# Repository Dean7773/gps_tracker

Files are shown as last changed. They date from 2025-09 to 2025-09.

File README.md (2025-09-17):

# 🛰️ GPS Tracker на ESP32

**GPS трекер с WiFi, SD картой и OLED дисплеем на базе ESP32**

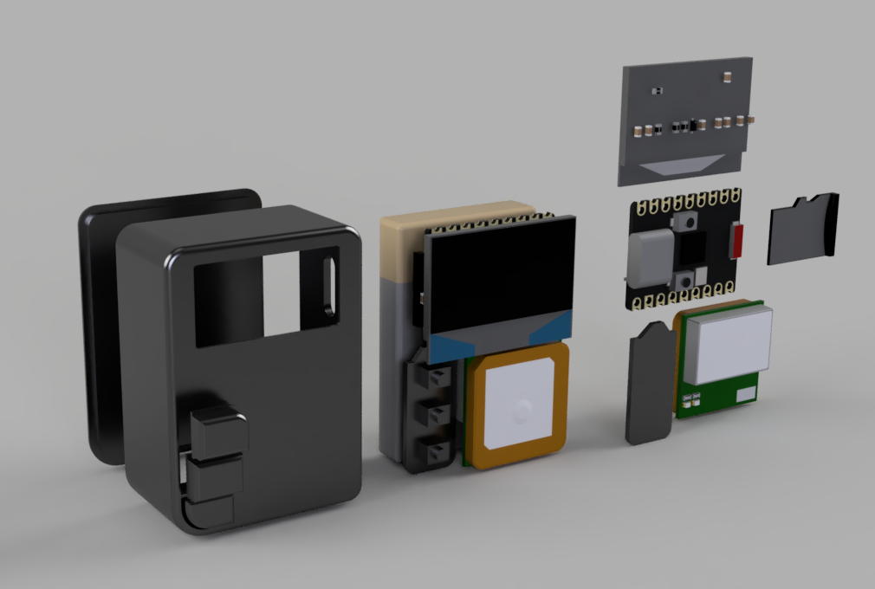
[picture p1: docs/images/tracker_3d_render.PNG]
ESP32 Tracker


## 📋 Описание

Это полнофункциональный GPS трекер, разработанный на ESP32-C3 с интуитивно понятным интерфейсом на OLED дисплее. Устройство способно записывать треки в высоком качестве, синхронизироваться с сервером через WiFi и управлять данными через удобное меню.

## Связанные проекты

- **[GPS Location Tracker](https://github.com/Dean7773/location_tracker)** - Сервис для просмотра маршрутов записанных при помощи GPS устройств.

## ✨ Основные возможности

### 🗺️ **GPS Трекинг**
- **Высокоточная запись** треков с фильтрацией по расстоянию (≥2м) и углу поворота (≥20°)
- **Поддержка GPS модуля** Cyclone M10-18 с автоматическим парсингом NMEA
- **Реальное время** из GPS спутников с поддержкой часовых поясов
- **Информация о спутниках** и качестве сигнала
- **Запись координат, высоты, скорости** и временных меток

### 📱 **Интерфейс и управление**
- **OLED дисплей 128x64** с четким отображением информации
- **Трехкнопочное управление** (UP/OK/DOWN) через аналоговый вход
- **Интуитивное меню** с навигацией по разделам
- **Информативные экраны** с детальной GPS информацией
- **Индикация статуса** записи и подключений

### 💾 **Хранение данных**
- **SD карта** для локального хранения треков
- **JSON формат** треков для совместимости с веб-сервисами
- **Управление файлами** - просмотр, удаление, форматирование
- **Тестирование SD карты** с диагностикой

### 🌐 **WiFi и синхронизация**
- **Автоматическое сканирование** и подключение к WiFi сетям
- **Сохранение до 3 сетей** в EEPROM с автоматическим переподключением
- **JWT авторизация** на сервере для безопасной передачи данных
- **Отправка треков чанками** для надежной передачи больших файлов
- **API интеграция** с веб-сервером для синхронизации данных

### 🔧 **Технические особенности**
- **Умная фильтрация точек** для оптимизации размера треков
- **Расчет расстояний и углов** поворота для точной записи
- **Обработка ошибок** и восстановление после сбоев
- **Энергоэффективность** с оптимизированным кодом
- **Модульная архитектура** для легкого расширения функций

## 🖼️ Интерфейс устройства

### Главное меню
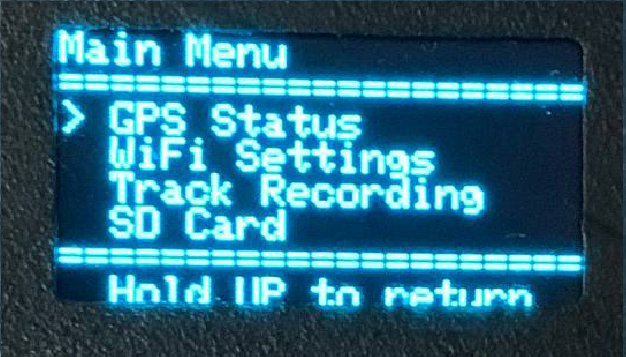
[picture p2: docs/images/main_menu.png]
Main Menu


*Главное меню с навигацией по основным разделам*

### GPS информация
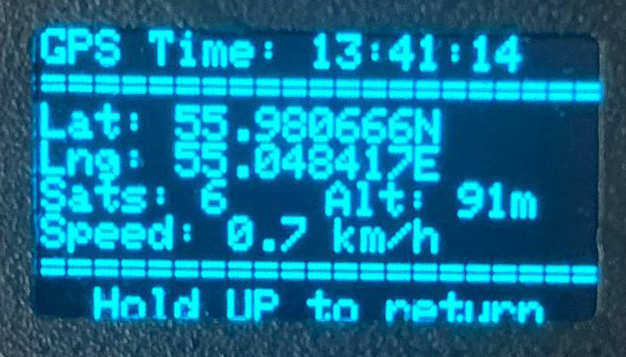
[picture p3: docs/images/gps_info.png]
GPS Info


*Детальная информация GPS: координаты, спутники, время, скорость*

### Запись трека
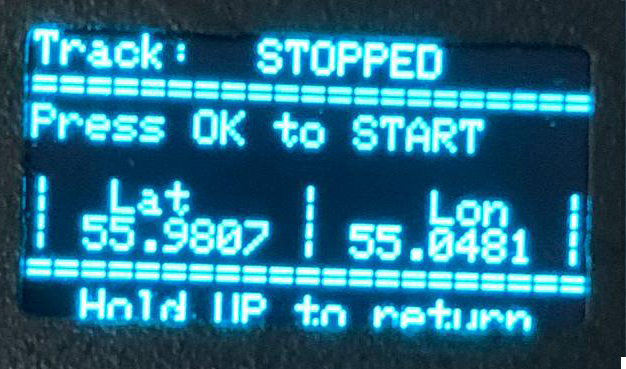
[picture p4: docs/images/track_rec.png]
Track Recording


*Интерфейс записи трека с индикацией количества точек*

### WiFi настройки
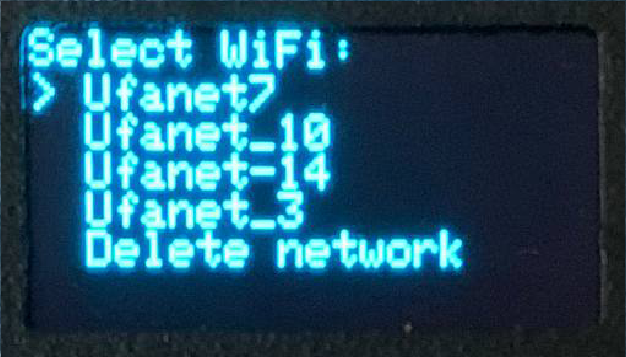
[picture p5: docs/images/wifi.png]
WiFi


*Управление WiFi подключениями и синхронизация с сервером*

### SD карта
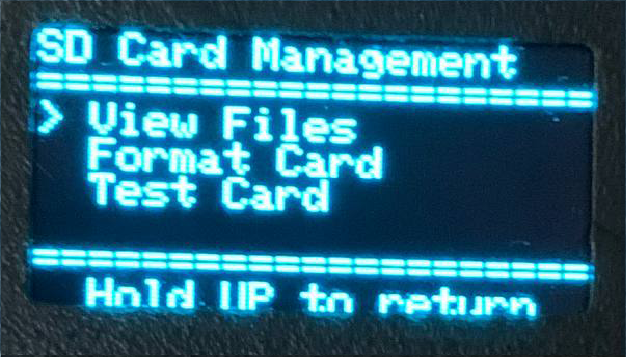
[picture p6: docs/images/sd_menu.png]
SD Menu


*Управление файлами на SD карте*

## 🔌 Аппаратная часть

### Компоненты
- **ESP32** (любая совместимая плата)
- **GPS модуль** Cyclone M10-18 (или совместимый)
- **OLED дисплей** 128x64 (SSD1306)
- **SD карта модуль** с поддержкой SPI
- **3 кнопки** для управления (через делитель напряжения)

### Схема подключения

```
ESP32 Pinout:
├── GPIO0  → Аналоговый вход кнопок (ADC1_CH1)
├── GPIO7  → SD Card CS (Chip Select)
├── GPIO20 → GPS RX (ESP32 RX ← GPS TX)
├── GPIO21 → GPS TX (ESP32 TX → GPS RX)
├── SDA    → OLED SDA
├── SCL    → OLED SCL
└── 3.3V/GND → Питание модулей
```

### Кнопки (делитель напряжения)
```
3.3V ─┬─ R1 ─┬─ UP Button ─┬─ GND
      │       │             │
      ├─ R2 ─┼─ OK Button ─┤
      │       │             │
      └─ R3 ─┴─ DOWN Button ┘
              │
              └─ GPIO0 (ADC)
```

## 🖥️ Внешний вид устройства
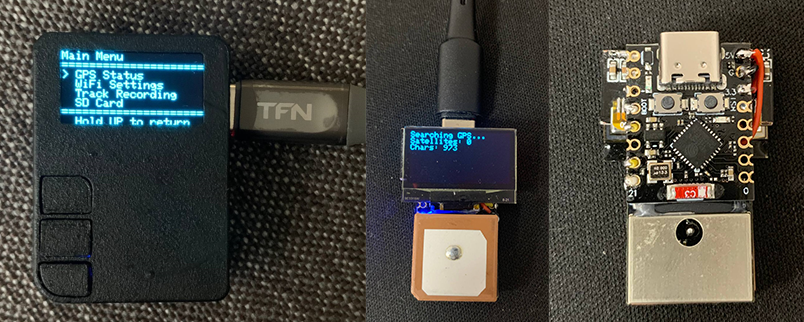
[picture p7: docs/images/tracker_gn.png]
Tracker Main


*Это макет, спроектированный на коленке, дизайн будет полностью изменен*

### Детали корпуса
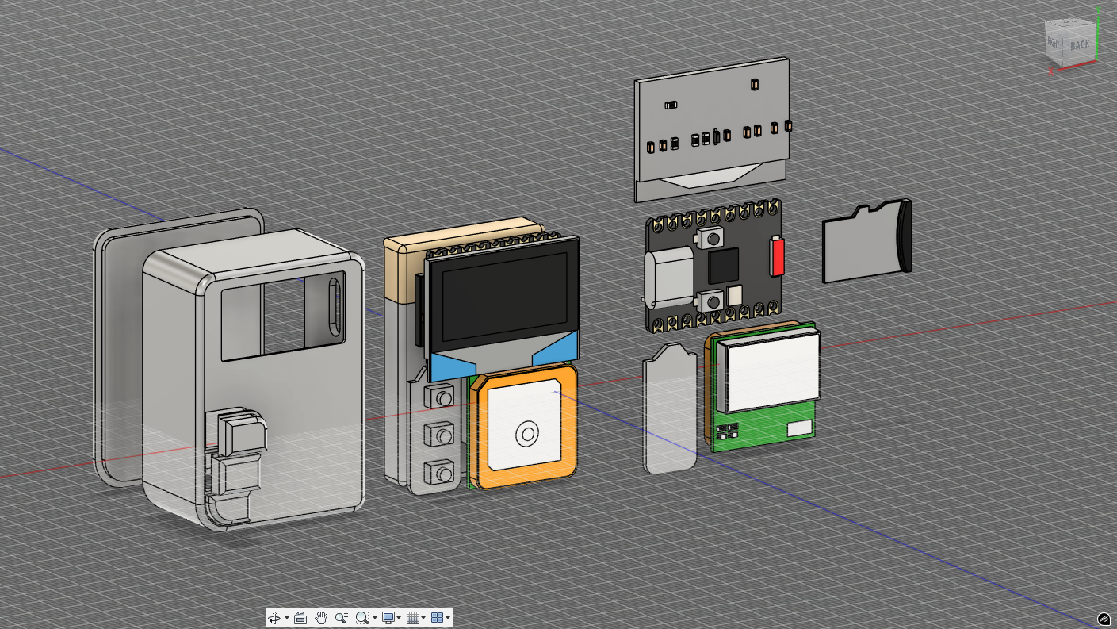
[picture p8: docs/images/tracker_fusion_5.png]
Tracker Top


*Части корпуса с размещением компонентов*

## 🚀 Установка и настройка

### 1. Установка Arduino IDE и библиотек

```cpp
// Необходимые библиотеки:
#include "EncButton.h"        // Обработка кнопок
#include <Adafruit_SSD1306.h> // OLED дисплей
#include <TinyGPS++.h>        // GPS парсинг
#include <WiFi.h>             // WiFi ESP32
#include <HTTPClient.h>       // HTTP клиент
#include <ArduinoJson.h>      // JSON обработка
#include <SD.h>               // SD карта
```

### 2. Настройка конфигурации

Отредактируйте `firmware/config.h`:

```cpp
// Настройка сервера
#define SERVER_URL "http://your-server.com:8000"

// Настройка пинов (при необходимости)
#define GPS_RX 20
#define GPS_TX 21
#define SD_CS_PIN 7
```

### 3. Прошивка устройства

1. Подключите ESP32 к компьютеру
2. Откройте `firmware/gps_tracker.ino` в Arduino IDE
3. Выберите плату ESP32 Dev Module
4. Загрузите прошивку

### 4. Первый запуск

1. Вставьте отформатированную SD карту
2. Включите устройство
3. Дождитесь GPS фикса (может занять 1-2 минуты)
4. Настройте WiFi через меню
5. Авторизация на сервере (требуется только для отправки треков)

## 🔧 Настройка и калибровка

### Калибровка кнопок
Измерьте напряжения на GPIO0 при нажатии кнопок и обновите в `config.h`:
```cpp
#define UP_MIN 1307    // Минимальное значение для UP
#define UP_MAX 1507    // Максимальное значение для UP
#define OK_MIN 2750    // Минимальное значение для OK
#define OK_MAX 2950    // Максимальное значение для OK
#define DOWN_MIN 4080  // Минимальное значение для DOWN
#define DOWN_MAX 4180  // Максимальное значение для DOWN
```

### Настройка фильтрации треков
В `tracks.ino` можно изменить параметры фильтрации:
```cpp
if (dist >= 2.0) {          // Минимальное расстояние между точками (метры)
  shouldWrite = true;
}
if (angle >= 20.0) {        // Минимальный угол поворота (градусы)
  shouldWrite = true;
}
```

## 📈 Производительность

### Характеристики записи
- **Точность GPS**: до 1-3 метров (зависит от условий)
- **Частота записи**: адаптивная (2м или 20° поворота)
- **Размер трека**: ~500 точек на км (зависит от маршрута)
- **Время работы**: 4-5 часов записи (с батареей 1000mAh)

### Объем данных
- **1 час записи**: ~5000 точек (~570 KB)
- **SD карта 1GB**: ~1,800 часов записи (75 дней)
- **Чанк для отправки**: 50 точек (~5.6 KB)

## 🛠️ Структура проекта

```
gps_tracker/
├── firmware/
│   ├── gps_tracker.ino    # Основной файл
│   ├── config.h           # Конфигурация
│   ├── menu.ino           # Интерфейс меню
│   ├── gps.ino            # GPS функции
│   ├── tracks.ino         # Запись и отправка треков
│   ├── wifi.ino           # WiFi управление
│   ├── sd.ino             # SD карта функции
│   └── auth.ino           # Авторизация
├── docs/
│   └── images/            # Скриншоты интерфейса
└── README.md
```

## 🐛 Устранение неполадок

### Частые проблемы

**GPS не получает фикс:**
- Проверьте подключение GPS модуля
- Убедитесь в наличии видимости неба
- Подождите 2-3 минуты для холодного старта

**SD карта не читается:**
- Проверьте формат (FAT32)
- Убедитесь в правильном подключении SPI
- Попробуйте другую SD карту

**WiFi не подключается:**
- Проверьте правильность пароля
- Убедитесь в поддержке 2.4GHz сети
- Перезагрузите устройство

**Кнопки не реагируют:**
- Проверьте делитель напряжения
- Откалибруйте значения в config.h
- Проверьте подключение к GPIO0

## 📝 Лицензия

Этот проект распространяется под лицензией MIT. См. файл [LICENSE](LICENSE) для подробностей.

## 🤝 Участие в разработке

Приветствуются любые улучшения! Для участия:

1. Сделайте Fork проекта
2. Создайте ветку для новой функции
3. Внесите изменения и протестируйте
4. Отправьте Pull Request

## 📞 Поддержка

Если у вас есть вопросы или предложения:
- Создайте Issue в GitHub
- Опишите проблему максимально подробно
- Приложите скриншоты и логи если возможно
- Напишите в тг: https://t.me/wlkks

## 🎯 Планы развития

- [ ] Энергосбережение и режимы сна
- [ ] Bluetooth интерфейс для настройки
- [ ] Поддержка дополнительных GPS форматов
- [ ] Веб-интерфейс для управления
- [ ] Мобильное приложение
- [ ] Поддержка LoRaWAN для дальней связи

---

**Создано с ❤️ для сообщества разработчиков GPS решений**

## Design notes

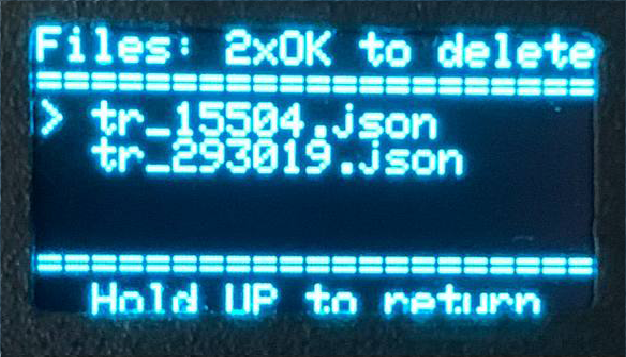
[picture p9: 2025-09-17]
docs/images/tracks_fs.png

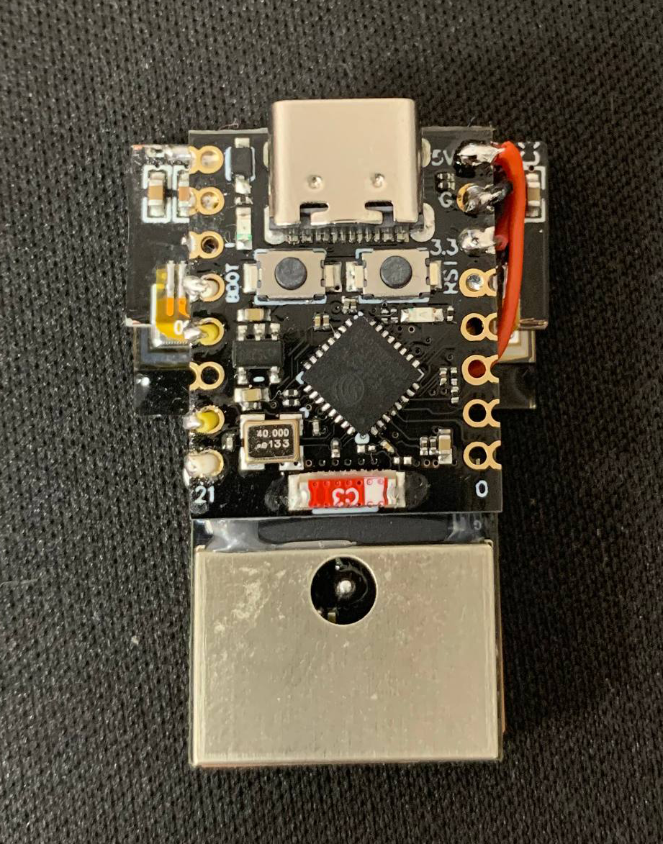
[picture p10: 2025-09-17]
docs/images/tracker_bttm.png

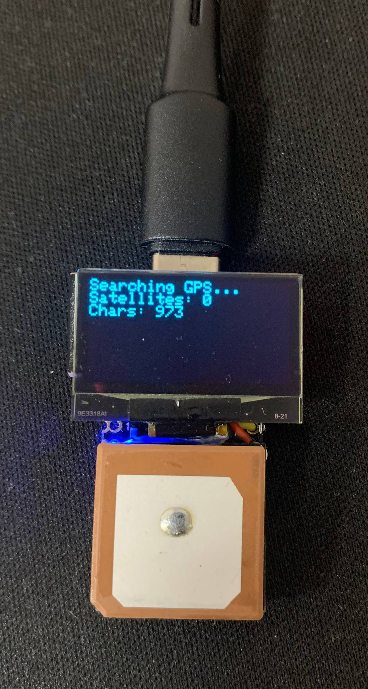
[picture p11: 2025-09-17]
docs/images/tracker_on.png

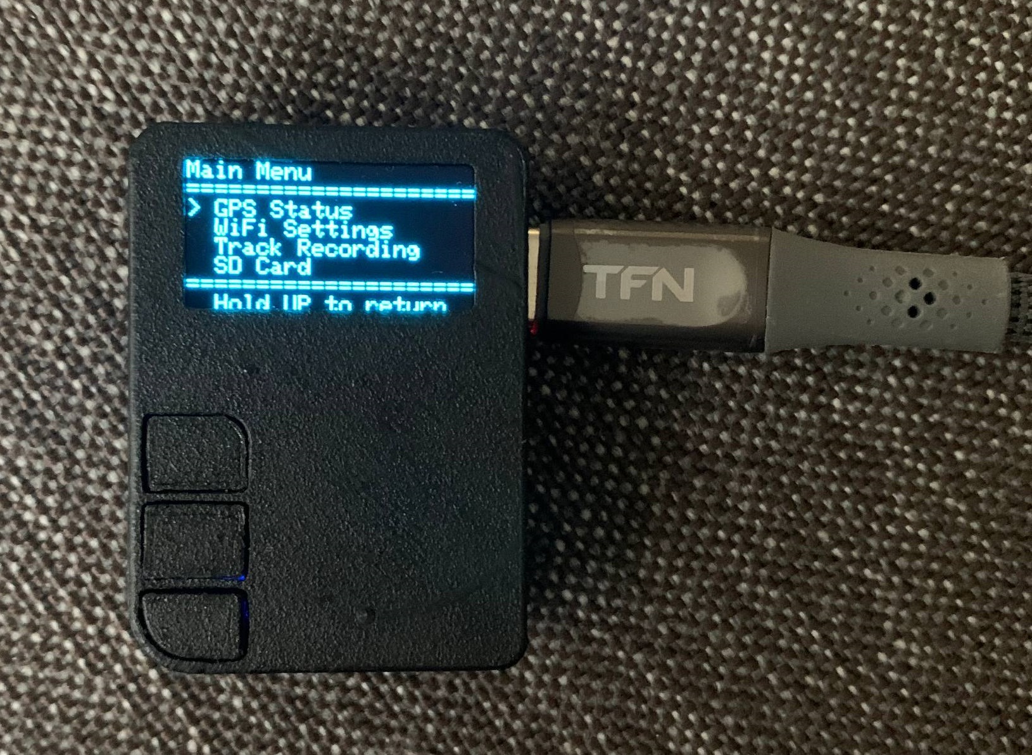
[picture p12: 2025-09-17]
docs/images/tracker_main.png

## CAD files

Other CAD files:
fusion360/gps_tracker.f3d

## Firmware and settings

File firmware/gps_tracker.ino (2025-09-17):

#include "EncButton.h"
#include <SPI.h>
#include <Wire.h>
#include <Adafruit_GFX.h>
#include <Adafruit_SSD1306.h>
#include <TinyGPS++.h>
#include <WiFi.h>
#include <HTTPClient.h>
#include <ArduinoJson.h>
#include <EEPROM.h>
#include <FS.h>
#include <SD.h>
#include <HardwareSerial.h>
#include <math.h>

#include "config.h"

// ============================================================================
// ИНИЦИАЛИЗАЦИЯ
// ============================================================================

// Инициализация OLED, GPS
Adafruit_SSD1306 display(SCREEN_WIDTH, SCREEN_HEIGHT, &Wire, OLED_RESET);
HardwareSerial gpsSerial(1);
TinyGPSPlus gps;

// Инициализация кнопок
VirtButton up;
VirtButton ok;
VirtButton down;

// ============================================================================
// СТРУКТУРЫ И ПЕРЕЧИСЛЕНИЯ
// ============================================================================

// Структура для хранения WiFi credentials
struct WiFiCred {
  char ssid[WIFI_CRED_MAXLEN];
  char pass[WIFI_CRED_MAXLEN];
};

// Перечисление для уровней меню
enum MenuLevel { MAIN, WIFI, TRACK, SDCARD, GPS };
MenuLevel menuLevel = MAIN;

// Переменные для указателей меню
uint8_t mainPointer = 0; // 0-GPS, 1-WiFi, 2-Track, 3-SD Card
uint8_t wifiPointer = 0; // 0-Connect/Connected, 1-Auth, 2-Send track, 3-Send all tracks
uint8_t sdPointer = 0;   // 0-Files, 1-Format, 2-Test
uint32_t elapsedTime = 0; // Оставляем для возможного использования в будущем
bool flag_track = false;
bool wifiConnected = false;

// WiFi меню
String ssidList[10];
int networksFound = 0;

// Символы для ввода пароля
const char symbols[] = "0123456789abcdefghijklmnopqrstuvwxyzABCDEFGHIJKLMNOPQRSTUVWXYZ!@#$%^&*()-_=+[]{};:,.<>/?";
const int symbolsCount = sizeof(symbols) - 1;

// Глобальные переменные для авторизации
String jwtToken = "";
String authUser = "";
String authPass = "";

// Переменные для отображения
static uint32_t lastDisplayUpdate = 0;
const uint32_t DISPLAY_UPDATE_INTERVAL = 500; // Обновление каждые 500мс

// Добавляем флаг для отрисовки
bool needRedraw = true;

// GPS данные для собственной обработки
struct GPSData {
  float latitude = 0;
  float longitude = 0;
  float speed = 0;
  uint8_t hours = 0;
  uint8_t minutes = 0;
  uint8_t seconds = 0;
  uint8_t satellites = 0;
  bool hasFix = false;
} gpsData;

// Переменные для записи трека
String currentTrackFile = "";
uint32_t trackPoints = 0;
uint32_t lastTrackWrite = 0;
uint32_t trackStartTime = 0; // Время начала записи трека
bool isRecording = false; // Флаг активной записи трека

// Переменные для фильтрации точек
float lastLat = 0.0, lastLon = 0.0;
float prevLat = 0.0, prevLon = 0.0; // Предыдущая точка для расчета угла
bool hasLastPoint = false;
bool hasPrevPoint = false; // Есть ли предыдущая точка для расчета угла


// --- Прототипы ---
int selectWiFiNetwork();
void inputPassword(char* password, int maxLen);
void connectToWiFi(const char* ssid, const char* password);
void disconnectWiFi();
void drawMainMenu();
void drawWiFiMenu();
void drawTrackMenu();
void drawSDCardMenu();
void inputString(char* buffer, int maxLen, const char* label, bool hide = false);
bool authorizeOnServer(const char* login, const char* pass, String& token, String& message);
void saveWiFiCredential(const char* ssid, const char* pass);
void loadWiFiCredentials(WiFiCred* creds);
void viewSDFiles();
void formatSDCard();
void testSDCard();
void deleteWiFiCredential(const char* ssid);
bool getSavedWiFiPassword(const char* ssid, char* password);
void configureGPS();
void readUBXData();
void startTrackRecording();
void stopTrackRecording();
void writeTrackPoint();
void sendTrackToServer(const char* filename);


void setup() {
  // Настройка аналогового входа для кнопок
  analogReadResolution(12); // 12-битное разрешение (0-4095)
  
  // Настройка задержки для hasClicks() - можно изменить по желанию
  ok.setClickTimeout(200);    // 400мс для OK (средне)

  display.begin(SSD1306_SWITCHCAPVCC, SCREEN_ADDRESS);
  display.clearDisplay();
  display.setTextSize(1);
  display.setTextColor(SSD1306_WHITE);
  display.setCursor(10, 10);
  display.println("Location tracker");
  display.display();
  delay(500);
  
  // Инициализация GPS через HardwareSerial для ESP32
  gpsSerial.begin(115200, SERIAL_8N1, GPS_RX, GPS_TX);
  delay(500);

  display.clearDisplay();
  display.display();
  drawMainMenu();
}

void loop() {

  // Читаем аналоговое значение кнопок
  int analog = analogRead(ANALOG_PIN);
  
  // Определяем нажатые кнопки
  bool upPressed = (analog >= UP_MIN && analog <= UP_MAX);
  bool okPressed = (analog >= OK_MIN && analog <= OK_MAX);
  bool downPressed = (analog >= DOWN_MIN && analog <= DOWN_MAX);
  
  // Обновляем состояния кнопок
  up.tick(upPressed);
  ok.tick(okPressed);
  down.tick(downPressed);
  
  // Дополнительная обработка кнопок для лучшей реакции
  if (flag_track) {
    up.tick(upPressed);
    ok.tick(okPressed);
    down.tick(downPressed);
  }


  // MAIN MENU
  if (menuLevel == MAIN) {
    if (up.click()) { mainPointer = (mainPointer + 3) % 4; needRedraw = true; }
    if (down.click()) { mainPointer = (mainPointer + 1) % 4; needRedraw = true; }
    if (ok.click()) {
      switch (mainPointer) {
        case 0: 
          menuLevel = GPS; 
          needRedraw = true;
          ok.reset(); 
          break;
        case 1: 
          menuLevel = WIFI; 
          wifiPointer = 0; 
          needRedraw = true; 
          ok.reset();
          break;
        case 2: 
          menuLevel = TRACK; 
          needRedraw = true; 
          ok.reset();
          break;
        case 3: 
          menuLevel = SDCARD; 
          sdPointer = 0; 
          needRedraw = true; 
          ok.reset();
          break;
      }
    }
    static uint32_t uiTimer = 0;
    if (millis() - uiTimer > 5000) { uiTimer = millis(); needRedraw = true; }
  }

  // WIFI SUBMENU
  if (menuLevel == WIFI) {
    int maxPointer = wifiConnected ? 4 : 1;
    if (up.click()) { wifiPointer = (wifiPointer + maxPointer - 1) % maxPointer; needRedraw = true; }
    if (down.click()) { wifiPointer = (wifiPointer + 1) % maxPointer; needRedraw = true; }
    if (ok.click()) {
      if (!wifiConnected) {
        int net = selectWiFiNetwork();
        if (net >= 0) {
          char password[33] = "";
          inputPassword(password, 33);
          connectToWiFi(ssidList[net].c_str(), password);
        }
        needRedraw = true;
      } else {
        switch (wifiPointer) {
          case 0: { // Connected
            display.clearDisplay();
            display.setCursor(0, 0);
            display.println("    Connected!");
            display.println("=====================");
            display.print("  IP: ");
            display.println(WiFi.localIP());
            display.println("");
            display.println(" Push to disconnect");
            display.println("");
            display.println("=====================");
            display.println("  Hold UP to return");
            display.display();
            while (true) {
              int analog = analogRead(ANALOG_PIN);
              bool upPressed = (analog >= UP_MIN && analog <= UP_MAX);
              bool okPressed = (analog >= OK_MIN && analog <= OK_MAX);
              
              up.tick(upPressed);
              ok.tick(okPressed);
              
              if (ok.click()) { disconnectWiFi(); needRedraw = true; break; }
              if (up.holding()) { needRedraw = true; break; }
              delay(1);
            }
            break;
          }
          case 1: { // Auth
            char login[33] = "";
            inputString(login, 33, "Login:");
            char pass[33] = "";
            inputString(pass, 33, "Password:", true);
            String token, msg;
            bool ok_auth = authorizeOnServer(login, pass, token, msg);
            display.clearDisplay();
            display.setCursor(0, 0);
            if (ok_auth) {
              display.println("Auth OK!");
              jwtToken = token;
              authUser = login;
              authPass = pass;
            } else {
              display.println("Auth failed!");
            }
            display.setCursor(0, 10);
            display.println(msg);
            display.setCursor(0, 24);
            display.println("Push to return");
            display.display();
            while (!ok.click()) { 
              int analog = analogRead(ANALOG_PIN);
              bool upPressed = (analog >= UP_MIN && analog <= UP_MAX);
              bool okPressed = (analog >= OK_MIN && analog <= OK_MAX);
              bool downPressed = (analog >= DOWN_MIN && analog <= DOWN_MAX);
              
              up.tick(upPressed);
              ok.tick(okPressed);
              down.tick(downPressed);
              delay(1); 
            }
            needRedraw = true;
            break;
          }
          case 2: { // Send track
            display.clearDisplay();
            display.setCursor(0, 0);
            display.println("Select track to send");
            display.println("Scanning SD...");
            display.display();
            
            // Сканируем SD карту на наличие треков
            if (SD.begin(SD_CS_PIN)) {
              File root = SD.open("/");
              if (root) {
                File entry = root.openNextFile();
                char trackFiles[20][32]; // Максимум 20 треков, каждый до 31 символа
                int trackCount = 0;
                
                // Собираем список треков
                while (entry && trackCount < 20) {
                  if (!entry.isDirectory()) {
                    strncpy(&trackFiles[trackCount][0], entry.name(), 31);
                    trackFiles[trackCount][31] = '\0'; // Гарантируем завершение строки
                    trackCount++;
                  }
                  entry.close();
                  entry = root.openNextFile();
                }
                root.close();
                
                if (trackCount > 0) {
                  // Показываем список треков для выбора
                  int selectedTrack = 0;
                  int scroll = 0;
                  const int visibleRows = 6; // Увеличено для экрана 64x128
                  
                  while (true) {
                    int analog = analogRead(ANALOG_PIN);
                    bool upPressed = (analog >= UP_MIN && analog <= UP_MAX);
                    bool okPressed = (analog >= OK_MIN && analog <= OK_MAX);
                    bool downPressed = (analog >= DOWN_MIN && analog <= DOWN_MAX);
                    
                    up.tick(upPressed);
                    ok.tick(okPressed);
                    down.tick(downPressed);
                    
                    if (up.click()) selectedTrack = (selectedTrack + trackCount - 1) % trackCount;
                    if (down.click()) selectedTrack = (selectedTrack + 1) % trackCount;
                    
                    // Скроллинг
                    if (selectedTrack < scroll) scroll = selectedTrack;
                    if (selectedTrack >= scroll + visibleRows) scroll = selectedTrack - visibleRows + 1;
                    
                    display.clearDisplay();
                    display.setCursor(0, 0);
                    display.println("Select track:");
                    
                    for (int i = 0; i < visibleRows; i++) {
                      int idx = scroll + i;
                      if (idx >= trackCount) break;
                      display.setCursor(0, 9 + i * 8);
                      if (idx == selectedTrack) display.print("> ");
                      else display.print("  ");
                      
                      // Обрезаем длинные имена
                      char shortName[20];
                      strncpy(shortName, trackFiles[idx], 18);
                      shortName[18] = '\0';
                      if (strlen(trackFiles[idx]) > 18) {
                        strcpy(shortName + 15, "...");
                      }
                      display.println(shortName);
                    }

                    display.display();
                    
                    if (ok.click()) {
                      // Отправляем выбранный трек
                      sendTrackToServer(trackFiles[selectedTrack]);
                      break;
                    }
                    if (up.holding()) break;
                    delay(1);
                  }
                }
              }
            }
            needRedraw = true;
            break;
          }
          case 3: { // Send all tracks
            display.clearDisplay();
            display.setCursor(0, 0);
            display.println("Send all tracks");
            display.println("Scanning SD...");
            display.display();
            
            // Сканируем SD карту на наличие треков
            if (SD.begin(SD_CS_PIN)) {
              File root = SD.open("/");
              if (root) {
                File entry = root.openNextFile();
                int trackCount = 0;
                while (entry) {
                  if (!entry.isDirectory()) {
                    trackCount++;
                  }
                  entry.close();
                  entry = root.openNextFile();
                }
                root.close();
                
                if (trackCount > 0) {
                  display.clearDisplay();
                  display.setCursor(0, 0);
                  display.print("Found ");
                  display.print(trackCount);
                  display.println(" tracks");
                  display.println("Push to send all");
                  display.println("Hold to cancel");
                  display.display();
                  
                  bool sendTracks = false;
                  while (true) {
                    int analog = analogRead(ANALOG_PIN);
                    bool upPressed = (analog >= UP_MIN && analog <= UP_MAX);
                    bool okPressed = (analog >= OK_MIN && analog <= OK_MAX);
                    bool downPressed = (analog >= DOWN_MIN && analog <= DOWN_MAX);
                    
                    up.tick(upPressed);
                    ok.tick(okPressed);
                    down.tick(downPressed);
                    
                    if (ok.click()) { sendTracks = true; break; }
                    if (up.holding()) break;
                    delay(1);
                  }
                  
                  if (sendTracks) {
                    // Отправляем все треки
                    root = SD.open("/");
                    if (root) {
                      entry = root.openNextFile();
                      while (entry) {
                        if (!entry.isDirectory()) {
                          sendTrackToServer(entry.name());
                        }
                        entry.close();
                        entry = root.openNextFile();
                      }
                      root.close();
                    }
                  }
                } else {
                  display.clearDisplay();
                  display.setCursor(0, 0);
                  display.println("No tracks found!");
                  display.println("Push to return");
                  display.display();
                  while (!ok.click()) { 
                    int analog = analogRead(ANALOG_PIN);
                    bool upPressed = (analog >= UP_MIN && analog <= UP_MAX);
                    bool okPressed = (analog >= OK_MIN && analog <= OK_MAX);
                    bool downPressed = (analog >= DOWN_MIN && analog <= DOWN_MAX);
                    
                    up.tick(upPressed);
                    ok.tick(okPressed);
                    down.tick(downPressed);
                    delay(1); 
                  }
                }
              }
            }
            needRedraw = true;
            break;
          }
        }
      }
    }
    if (up.holding()) { menuLevel = MAIN; needRedraw = true; }
  }

  // TRACK MENU
  if (menuLevel == TRACK) {
    // Приоритетная обработка кнопок
    if (ok.click()) { 
      if (!flag_track) {
        // Начинаем запись трека
        flag_track = true;
        startTrackRecording();
      } else {
        // Останавливаем запись трека - немедленно
        flag_track = false;
        stopTrackRecording();
      }
      needRedraw = true; 
    }
    if (up.holding()) { menuLevel = MAIN; needRedraw = true; }
    
    // Запись GPS точек во время трека - 2 раза в секунду для лучшей реакции
    if (isRecording && millis() - lastTrackWrite > 500) { // 1000ms / 2 = 500ms
      lastTrackWrite = millis();
      writeTrackPoint();
      needRedraw = true;
    }
    
    // Дополнительная обработка нажатий во время записи
    if (isRecording) {
      int analog = analogRead(ANALOG_PIN);
      bool upPressed = (analog >= UP_MIN && analog <= UP_MAX);
      bool okPressed = (analog >= OK_MIN && analog <= OK_MAX);
      bool downPressed = (analog >= DOWN_MIN && analog <= DOWN_MAX);
      
      up.tick(upPressed);
      ok.tick(okPressed);
      down.tick(downPressed);
    }
  }

  // GPS MENU
  if (menuLevel == GPS) {
    // Отладка входа в GPS меню (только один раз)
    static bool gpsEntered = false;
    if (!gpsEntered) {
      gpsEntered = true;
      needRedraw = true;

    }
    
    if (ok.click() || up.holding()) { 
      menuLevel = MAIN; 
      needRedraw = true; 
      gpsEntered = false;
    }
    
    // Безопасное чтение GPS данных
    static uint32_t lastGPSUpdate = 0;
    if (millis() - lastGPSUpdate > 2000) { // Обновляем каждые 2 секунды
      lastGPSUpdate = millis();
      
      // Читаем GPS данные
      while (gpsSerial.available()) {
        char c = gpsSerial.read();
        gps.encode(c);
      }
      needRedraw = true;
    }
  }

  // SDCARD MENU
  if (menuLevel == SDCARD) {
    if (up.click()) { sdPointer = (sdPointer + 2) % 3; needRedraw = true; }
    if (down.click()) { sdPointer = (sdPointer + 1) % 3; needRedraw = true; }
    if (ok.click()) {
      switch (sdPointer) {
        case 0: viewSDFiles(); needRedraw = true; break;
        case 1: formatSDCard(); needRedraw = true; break;
        case 2: testSDCard(); needRedraw = true; break;
      }
    }
    if (up.holding()) { menuLevel = MAIN; needRedraw = true; }
  }

  // ОТРИСОВКА ТОЛЬКО ЕСЛИ НУЖНО
  if (needRedraw) {
    switch (menuLevel) {
      case MAIN: drawMainMenu(); break;
      case WIFI: drawWiFiMenu(); break;
      case TRACK: drawTrackMenu(); break;
      case SDCARD: drawSDCardMenu(); break;
      case GPS: drawGPSMenu(); break;
    }
    needRedraw = false;
  }
}

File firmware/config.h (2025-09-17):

// ============================================================================
// КОНФИГУРАЦИЯ ПИНОВ И НАСТРОЕК
// ============================================================================

// Пин для аналогового чтения кнопок
#define ANALOG_PIN 0  // GPIO0 (ADC1_CH1)

// Диапазоны напряжения для каждой кнопки
#define UP_MIN 1307    // Минимальное значение для кнопки UP
#define UP_MAX 1507    // Максимальное значение для кнопки UP
#define OK_MIN 2750    // Минимальное значение для кнопки OK
#define OK_MAX 2950    // Максимальное значение для кнопки OK
#define DOWN_MIN 4080  // Минимальное значение для кнопки DOWN
#define DOWN_MAX 4180  // Максимальное значение для кнопки DOWN

// GPS подключение
#define GPS_RX 20  // ESP32 RX (подключается к TX GPS)
#define GPS_TX 21  // ESP32 TX (подключается к RX GPS)

// OLED подключение
#define SCREEN_WIDTH 128
#define SCREEN_HEIGHT 64
#define OLED_RESET     -1
#define SCREEN_ADDRESS 0x3C

// WiFi credentials
#define WIFI_CRED_MAXLEN 32
#define WIFI_CRED_COUNT 3
#define EEPROM_SIZE (WIFI_CRED_COUNT * WIFI_CRED_MAXLEN * 2)

// SD карта подключение
#define SD_CS_PIN 7

// Константы для API
#define SERVER_URL "http://192.168.0.112:8000"
#define API_AUTH_ENDPOINT "/api/v1/auth/login"
#define API_TRACKS_ENDPOINT "/api/v1/tracks/upload"
#define API_TRACKS_CHUNK_ENDPOINT "/api/v1/tracks/load_from_tracker"

// Отправка трека чанками
#define CHUNK_SIZE 50          // Оптимальный размер ~5.6KB для ESP32-C3

// Радиус Земли
#define EARTH_RADIUS_M 6371000.0
